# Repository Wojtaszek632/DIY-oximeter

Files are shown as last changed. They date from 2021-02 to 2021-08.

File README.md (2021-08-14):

# DIY oximeter
Atmega328p with custom PCB designed to monitor pulse and O2 level. Created as Final project for Embeded systems course.demo02
Schematic_Projekcik_2021-01-20_10-31-11

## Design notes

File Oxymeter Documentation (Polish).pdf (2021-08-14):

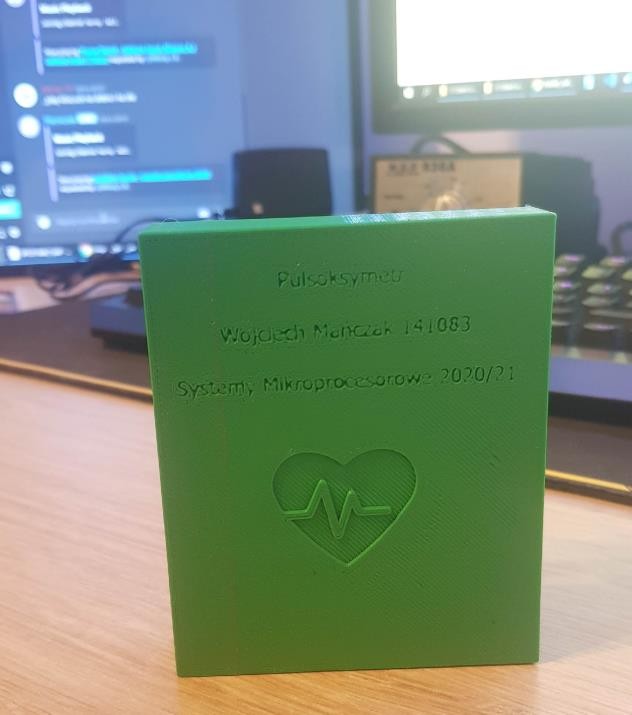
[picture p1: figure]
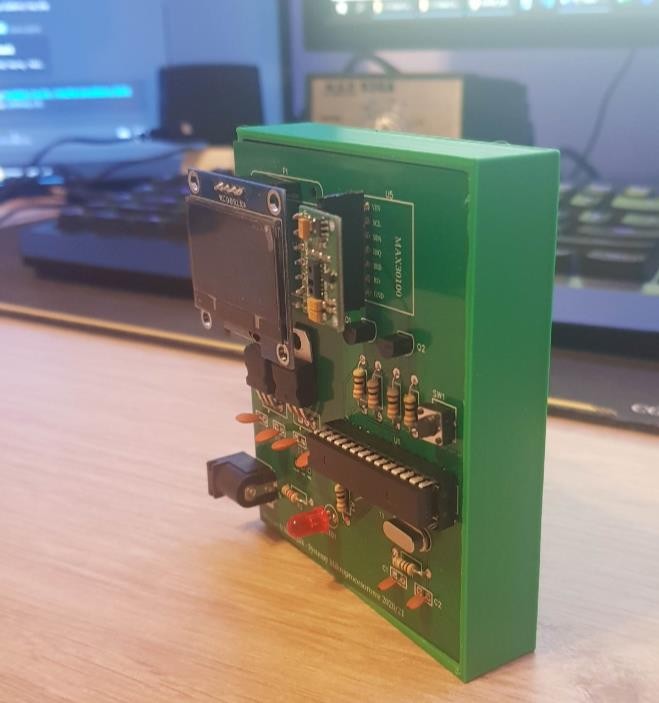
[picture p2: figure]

Systemy Mikroprocesorowe – kierunek AiR na WI - Politechnika Poznańska 2020

## Karta projektu zaliczeniowego części zadaniowej egzaminu Systemy mikroprocesorowe - 2020

Temat projektu: Pulsoksymetr

### Imię i nazwisko: Wojciech Mańczak

Nr albumu: 141083

Kierunek: AiR, grupa: A3,

### 1. Opis projektu

Pomysł na projekt powstał w czasie izolacji domowej spowodowanej pozytywnym wynikiem SARS-CoV-2. Jednym z zaleceń WHO jest systematyczne mierzenie natlenienia krwi przy użyciu pulsoksymetrów. Z powodu pandemii, ich ilość została ograniczona, dlatego postanowiłem zbudować go własnoręcznie. Układ opiera się o czujnik pulsu i natlenienia krwi - MAX30100 oraz wyświetlacz OLED z kontrolerem I2C SH1106. Całość kontrolowana przez Atmega328p z bootloader’em arduino. Zasilanie z zewnętrznego źródła poprzez złącze DC Jack 5.5 mm, stabilizowane przez układ do potrzebnych napięć. Całość zamknięta w obudowie wydrukowanej na drukarce Ender 3 PRO oraz zaprojektowanej w Autodesk Inventor.

Rysunek 1. 1 Schemat blokowy systemu

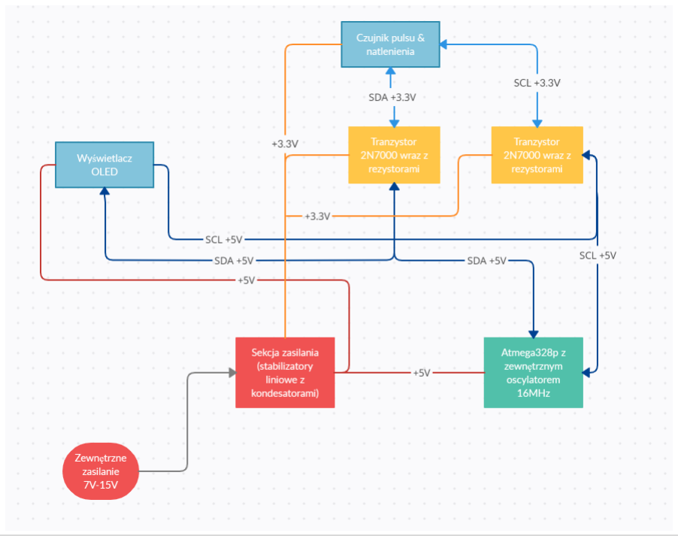
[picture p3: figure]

### 2. Hardware

Tabela 2. 1 Spis najważniejszych elementów

Atmega 328p

Pulsometr MAX30100 wraz z regulatorem 3.3V -> 1.8V napięcia oraz peryferiami. Komunikacja przy użyciu I2C.

Wyświetlacz OLED, wraz z wbudowanym kontrolerem SH1106. Komunikacja przy użyciu I2C.

Stabilizator liniowy 5V L7805CV

Stabilizator liniowy LDO 3,3V LD1117V33

Tranzystor N-MOSFET 2N7000

Dodatkowo, aby zagwarantować poprawna prace powyższych elementów, użyto: Złącze DC Jack 5.5mm/2.1mm
Kondensatory ceramiczne 100nF
Kondensatory ceramiczne 22pF
Podstawka do układów DIP 28-pinowa LED 5mm czerwony
Oscylator kwarcowy 16MHz
Tact switch - 2 pinowy
Rezystor 10kΩ
Rezystor 220Ω

Schemat elektroniczny układu, zaprojektowany oraz narysowany przy pomocny narzędzia EasyEDA¹

:

Rysunek 2. 1 Schemat elektroniczny układu

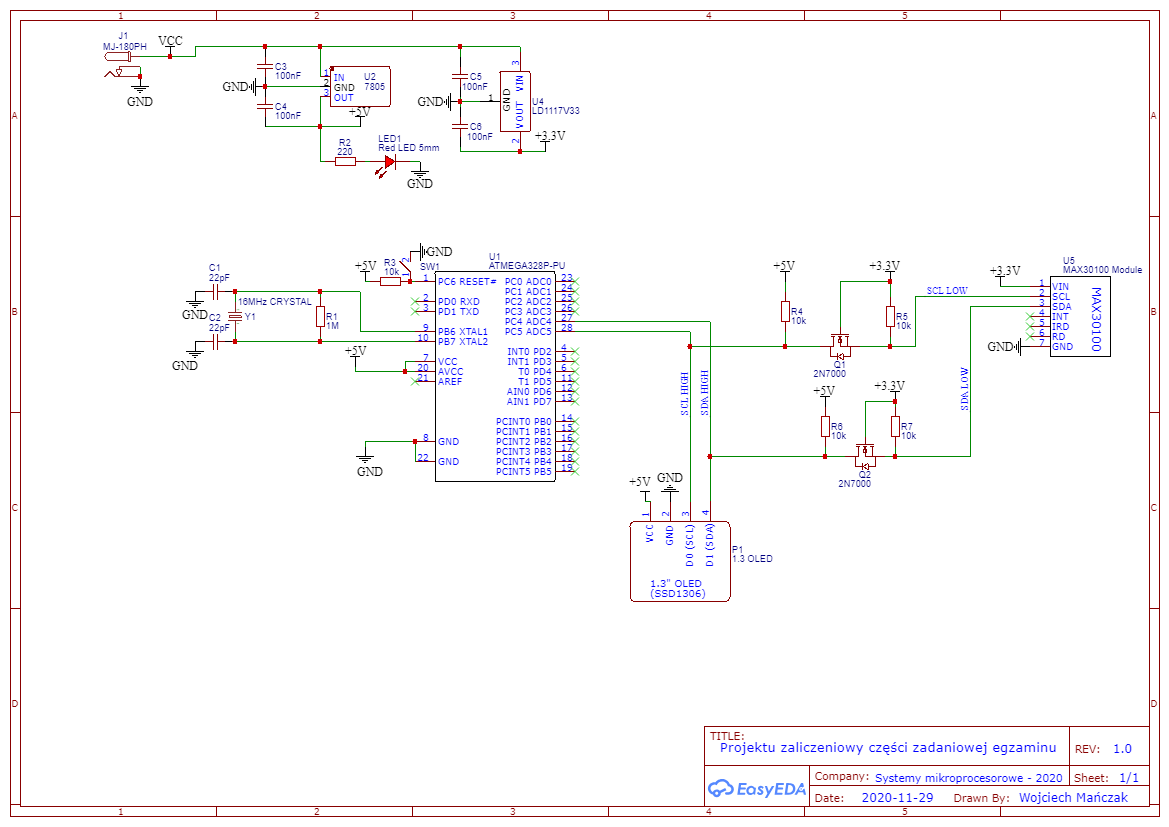
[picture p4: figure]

1 EasyEDA – Symulator obwodów i konstrukcja PCB Online - https://easyeda.com

Schemat płytki drukowanej, zaprojektowany przy pomocny narzędzia EasyEDA oraz wytworzonej przez firmę JLCPCB²

:

Rysunek 2. 2 Górna warstwa płytki drukowanej

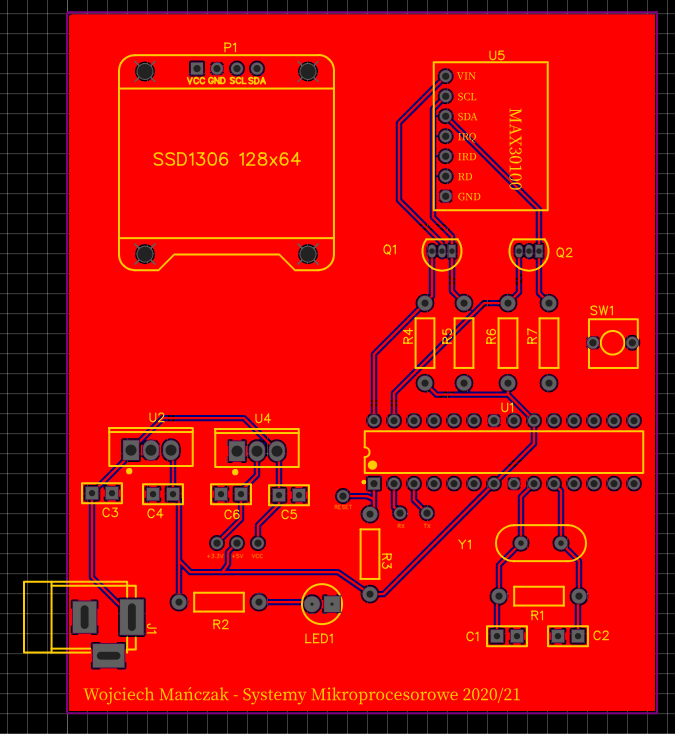
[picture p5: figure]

Rysunek 2. 3 Dolna warstwa płytki drukowanej

2

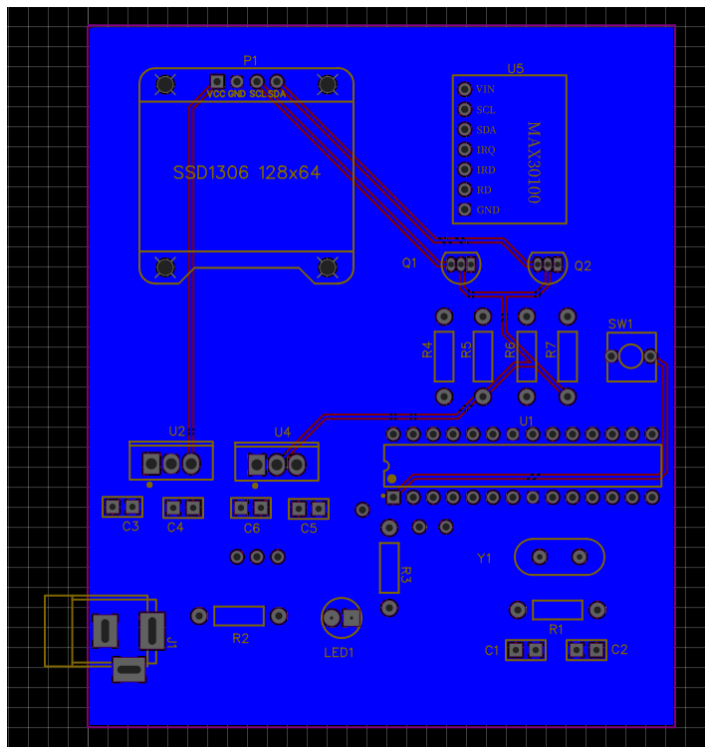
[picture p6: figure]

JLCPCB PCB Manufacturing - https://jlcpcb.com

Rysunek 2. 4 Front płytki drukowanej

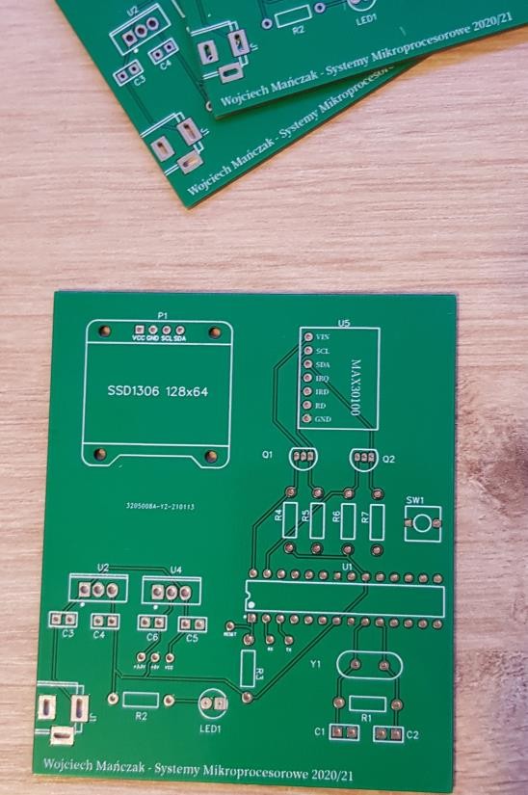
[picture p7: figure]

Rysunek 2. 5 tył płytki drukowanej

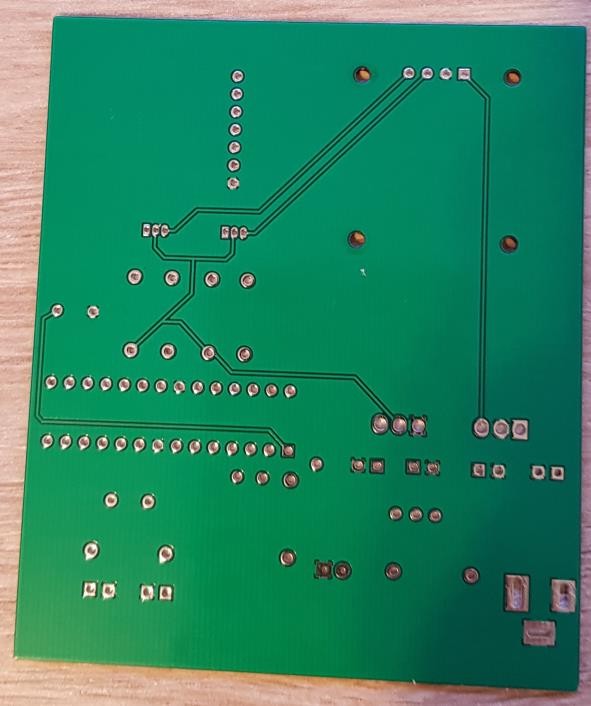
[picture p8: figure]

### 3. Software

Rysunek 3. 1 Schemat Blokowy programu

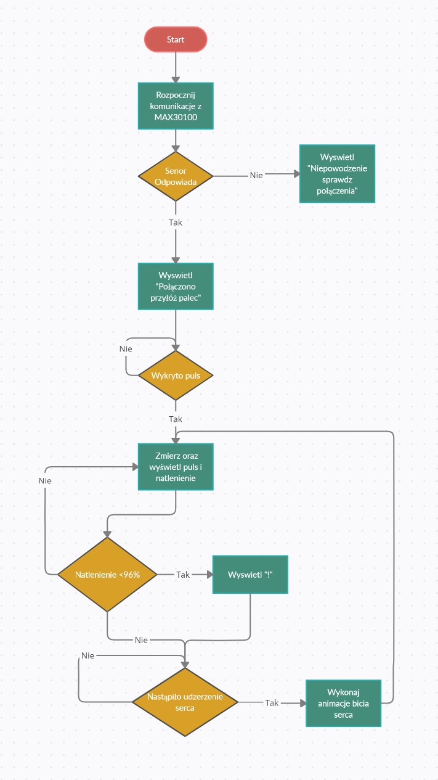
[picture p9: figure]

Ponieważ atmega328p użyta w układzie została wypalona z bootload’erm arduino korzystamy ze środowiska Arduino IDE oraz edytora Visual Studio Code. Dzięki temu mamy dostęp do bibliotek obsługujących czujnik pulsu oraz wyświetlacz OLED.

Wykorzystane biblioteki:
Wire.h³
- komunikacja po I2C
MAX30100_PulseOximeter.h⁴
- obsługa pomiarów pulsu oraz natlenienia MAX30100 MAX30100.h⁵
- obsługa wbudowanych zabezpieczeń czujnika MAX30100 U8g2lib.h⁶
- biblioteka do graficznej obsługi monochromatycznych wyświetlaczy

3 Biblioteka Arduino - https://www.arduino.cc/en/reference/wire

4 Biblioteka dostarczona przez producenta - OXullo Intersecans - https://github.com/oxullo/Arduino-MAX30100/blob/master/src/MAX30100_PulseOximeter.h

5 Biblioteka dostarczona przez producenta - OXullo Intersecans - https://github.com/oxullo/Arduino-MAX30100

6 Biblioteka stworzona przez użytkownika – olikraus - https://github.com/olikraus/u8glib

Podczas budowania prototypu układu na płytce stykowej, posługiwałem się Arduino Uno, które po skończeniu prac, posłużyło również do wypalenia bootload’era oraz wgrania programu do Atmegi 328p. Całość wykonana została przy użyciu środowiska Arduino IDE oraz wbudowanego w Arduino UNO programatora.

Najważniejsze elementy programu:

Rysunek 3. 2 Rozpoczęcie komunikacji oraz ustawienie parametrów sugerowanych przez producenta

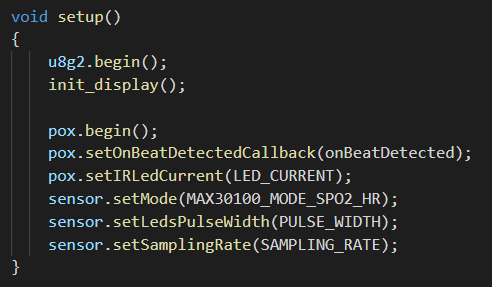
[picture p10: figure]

Rysunek 3. 3 Obsługa połączenia z czujnikiem MAX30100

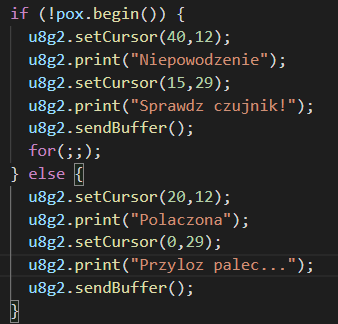
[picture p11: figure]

Rysunek 3. 4 Pomiar pulsu oraz natlenienia

Rysunek 3. 5 wyświetlanie pulsu oraz natlenienia

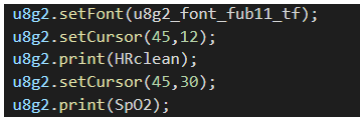
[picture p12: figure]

### 4. Proces montażu i programowania systemu

Proces budowy rozpoczął się od narysowania schematu ideowego, zapoznania się z dokumentacją a następnie narysowaniu schematu elektrycznego.
Następnie powstał prototyp układu. Początkowo oparty o logikę Arduino UNO, lecz w późniejszych krokach pojawiła się już Atmega328p z bootlooaderem Arduino (Uno służy tutaj jedynie jako połączenie do zasilacza 12V).

Rysunek 5. 1 Pierwszy działający prototyp

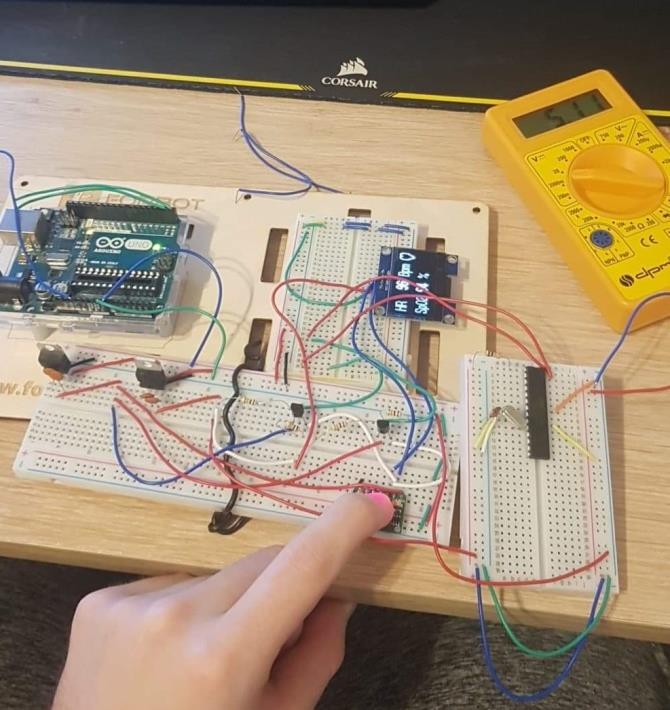
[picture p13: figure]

Następnie zaprojektowana i zamówiona została płytka PCB:

Rysunek 5. 2 Odbiór płytek PCB

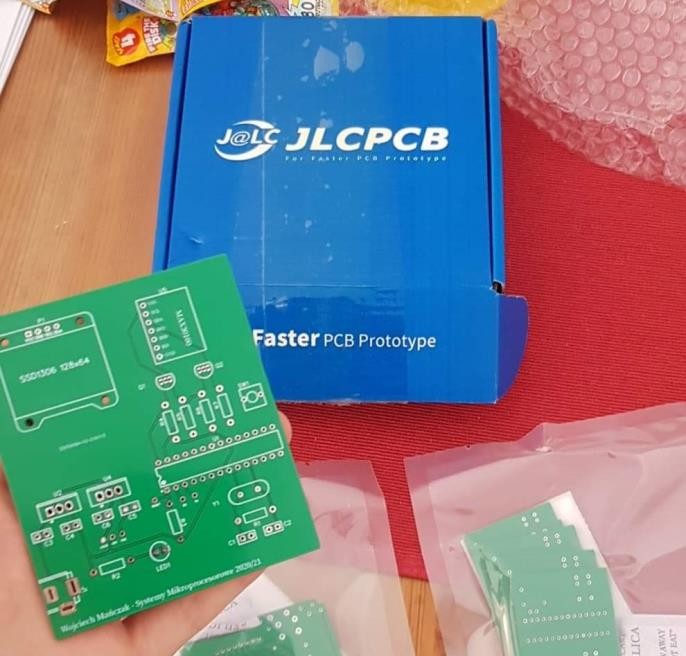
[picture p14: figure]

Rysunek 5. 3 Proces przylutowywania elementów do PCB

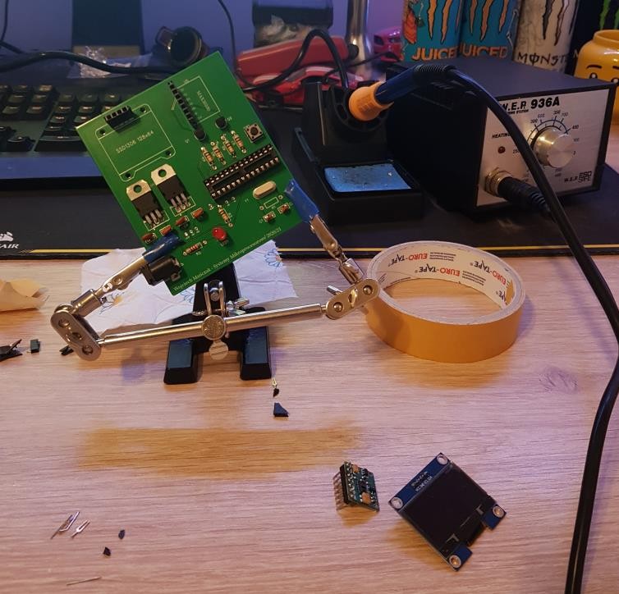
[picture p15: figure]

Rysunek 5. 4 Pierwsze testy sekcji zasilania

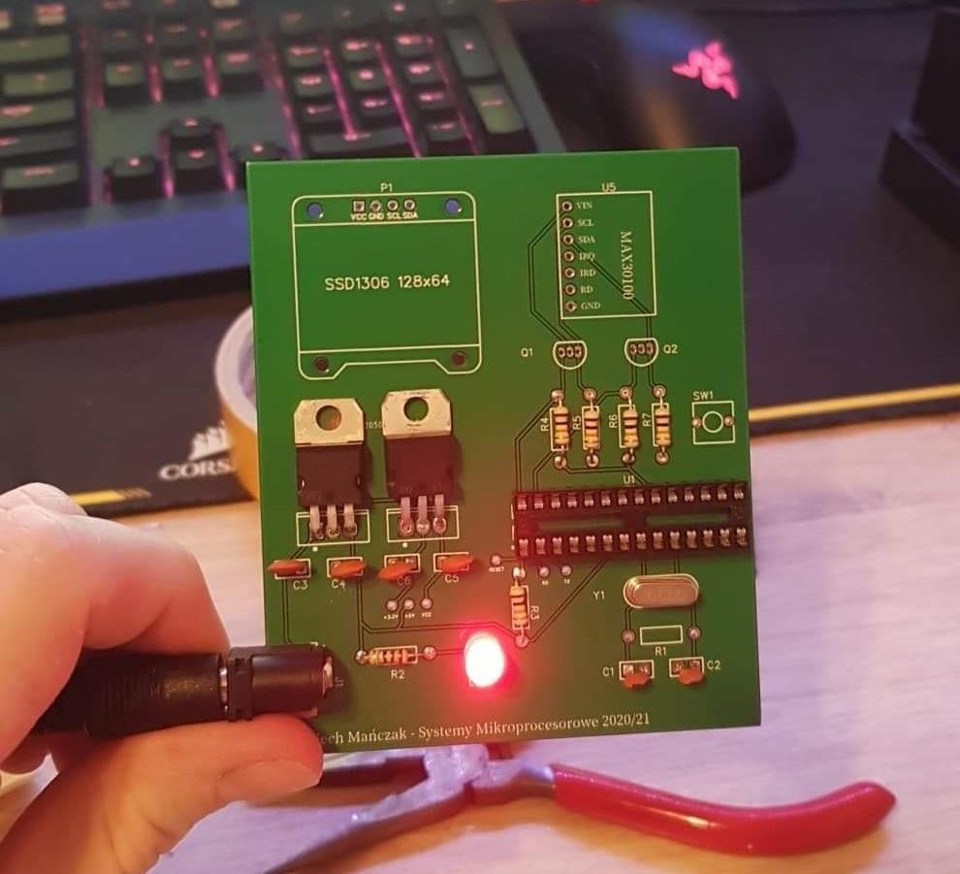
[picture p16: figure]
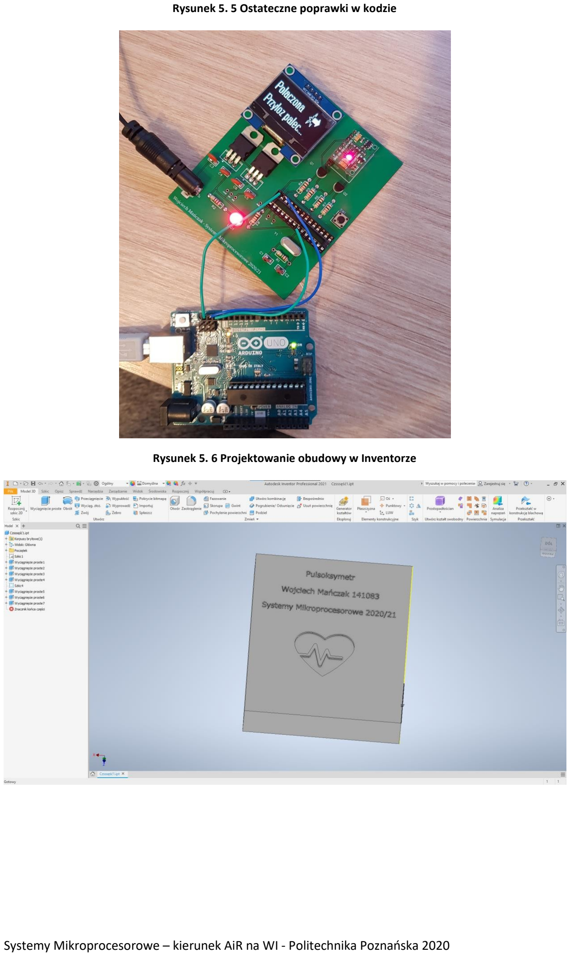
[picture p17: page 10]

Rysunek 5. 5 Ostateczne poprawki w kodzie

Rysunek 5. 6 Projektowanie obudowy w Inventorze

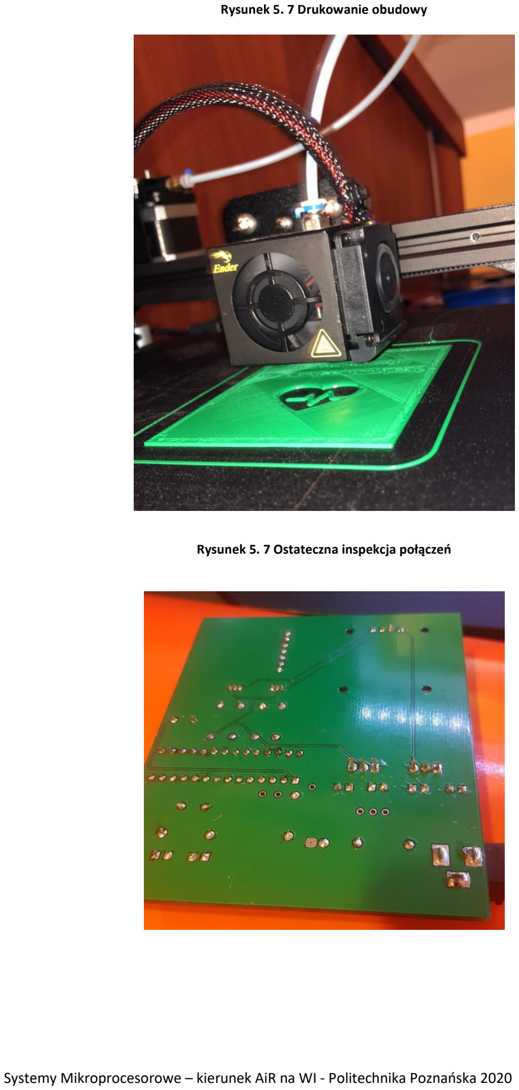
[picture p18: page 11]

Rysunek 5. 7 Drukowanie obudowy

Rysunek 5. 7 Ostateczna inspekcja połączeń

### 5. Weryfikacja poprawności działania układu

Rysunek 5. 8 Poprawne połączenie z czujnikiem, oczekiwanie na użytkownika

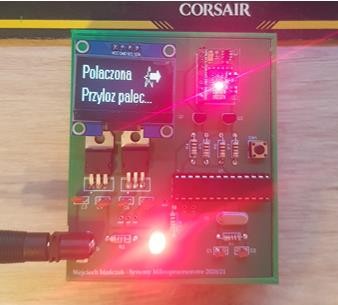
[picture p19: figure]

Rysunek 5. 9 Wykonywanie pomiaru

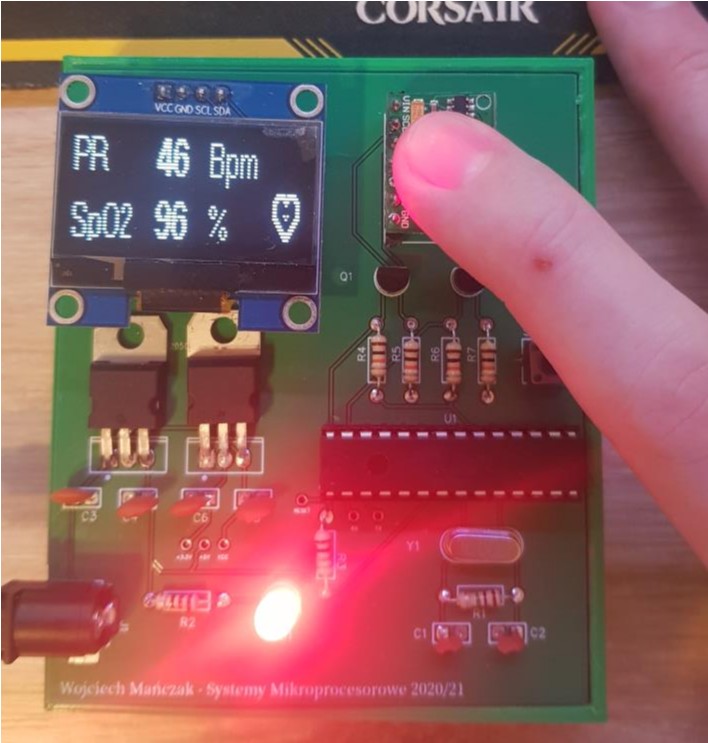
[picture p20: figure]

### 6. Obsługa układu

Obsługa układu rozpoczyna się od podłączenia zasilania do portu DC jack. Układ może być zasilany z zewnętrznego zasilacza ( Max 15V z powodu nie chłodzonej sekcji zasilania) lub z baterii 9V.
Po dostarczeniu zasilania układ uruchamia się samodzielnie. Dokonuje próby połączenia z czujnikiem, i prosi użytkownika o przyłożenie palca. Należy wtedy przyłożyć palec do czerwonej diody LED, i nie poruszać nim. Wyświetlone zostanie serce jeżeli użytkownik prawidłowo umieścił palec. Układ wykonuje pomiary w czasie rzeczywistym, więc chwilowe zakłamania wartości zostaną szybko skorygowane. Jeżeli układ wykryje za niskie natlenienie krwi wyświetli ostrzeżenie w postaci „!”. Dodatkowo w momencie uderzenia serca (monitorowanie na żywo) wykonana zostanie animacja pulsowania serca.

### 7. Literatura

Forum robotyczne Forbot - https://forbot.pl/blog/
Symulator obwodów i konstrukcja PCB Online - https://easyeda.com
Strona platformy Arduino - https://www.arduino.cc/en
Strona GitHub producenta MAX30100 - OXullo Intersecans - https://github.com/oxullo Strona GitHub użytkownika – olikraus - https://github.com/olikraus

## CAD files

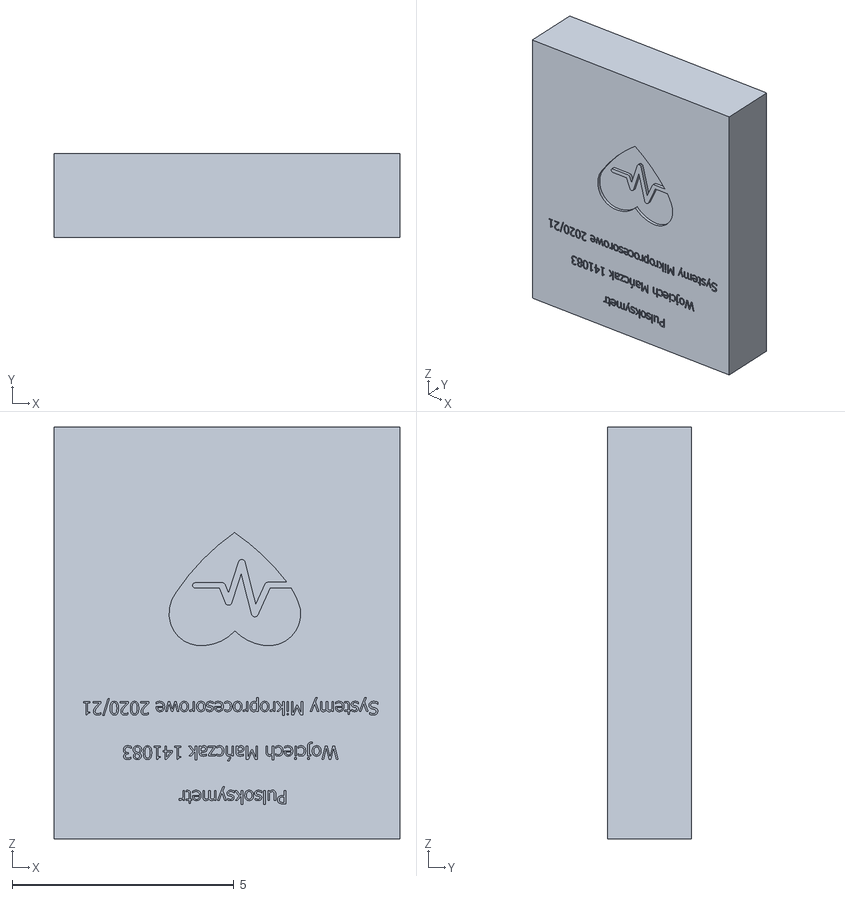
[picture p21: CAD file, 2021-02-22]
Case.stl
7.80 x 1.90 x 9.30

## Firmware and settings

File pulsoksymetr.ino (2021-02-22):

/* Projekt zaliczeniowy części zadaniowej egzamniu Systemy Mikroprocesorowe 2020/21
 *  Atmega328p
 *  MAX30100 
 *  OLED SH1106 
 *  Wojciech Mańczak 141083
*/

#include <Wire.h>
#include "MAX30100_PulseOximeter.h"
#include "MAX30100.h"
#include <U8g2lib.h>

#define REPORTING_PERIOD_MS 1000
#define PULSE_WIDTH MAX30100_SPC_PW_1600US_16BITS
#define IR_LED_CURRENT MAX30100_LED_CURR_40MA
#define LED_CURRENT MAX30100_LED_CURR_20_8MA
#define SAMPLING_RATE MAX30100_SAMPRATE_100HZ

U8G2_SH1106_128X32_VISIONOX_F_HW_I2C u8g2(U8G2_R0);
PulseOximeter pox;
MAX30100 sensor;

uint32_t tsLastReport = 0;

bool OledReady = false;
int HeartRate;
int SpO2;

void onBeatDetected()
{
  u8g2.setFont(u8g2_font_cursor_tf);
  u8g2.setCursor(119, 25);
  u8g2.print("^");
  u8g2.sendBuffer();
}

void init_oled()
{
  if (!OledReady)
  {
    u8g2.clearBuffer();
    u8g2.setCursor(28, 13);
    u8g2.setFont(u8g2_font_crox2hb_tr);
    u8g2.print("Laczenie z");
    u8g2.setFont(u8g2_font_crox2h_tr);
    u8g2.setCursor(31, 30);
    u8g2.print("czujnikiem...");
    u8g2.sendBuffer();
    delay(1000);

    OledReady = true;

    u8g2.clearBuffer();
    u8g2.setFont(u8g2_font_crox2hb_tr);
    if (!pox.begin())
    {
      u8g2.setCursor(1, 13);
      u8g2.print("Niepowodzenie");
      u8g2.setCursor(1, 30);
      u8g2.print("Sprawdz czujnik!");
      u8g2.sendBuffer();
      for (;;)
        ;
    }
    else
    {
      u8g2.setCursor(1, 13);
      u8g2.print("Polaczona");
      u8g2.setCursor(1, 30);
      u8g2.print("Przyloz palec...");

      u8g2.setFont(u8g2_font_cursor_tf);
      u8g2.setCursor(100, 9);
      u8g2.print("➑");

      u8g2.sendBuffer();
    }
    delay(2000);
  }
}

void setup()
{
  u8g2.begin();
  init_oled();

  pox.begin();
  pox.setOnBeatDetectedCallback(onBeatDetected);
  pox.setIRLedCurrent(LED_CURRENT);
  sensor.setMode(MAX30100_MODE_SPO2_HR);
  sensor.setLedsPulseWidth(PULSE_WIDTH);
  sensor.setSamplingRate(SAMPLING_RATE);
}

void loop()
{
  pox.update();
  HeartRate = pox.getHeartRate();
  SpO2 = pox.getSpO2();

  if (millis() - tsLastReport > REPORTING_PERIOD_MS)
  {
    if (HeartRate > 30 & HeartRate<220 & SpO2> 30 & SpO2 < 100)
    {
      u8g2.clearBuffer();

      u8g2.setFont(u8g2_font_crox2h_tr);
      u8g2.setCursor(0, 12);
      u8g2.print("PR");

      u8g2.setCursor(76, 13);
      u8g2.print("Bpm");

      u8g2.setCursor(0, 31);
      u8g2.print("SpO2 ");

      u8g2.setCursor(76, 31);
      u8g2.print("%");

      u8g2.setFont(u8g2_font_fub11_tf);
      u8g2.setCursor(46, 13);
      u8g2.print(HeartRate);

      u8g2.setCursor(46, 31);
      u8g2.print(SpO2);

      if (SpO2 <= 95)
      {
        u8g2.setCursor(90, 31);
        u8g2.print("!");
      }
      u8g2.setFont(u8g2_font_cursor_tf);

      u8g2.setCursor(119, 25);
      u8g2.print("_");

      u8g2.sendBuffer();
    }
    tsLastReport = millis();
  }
}
